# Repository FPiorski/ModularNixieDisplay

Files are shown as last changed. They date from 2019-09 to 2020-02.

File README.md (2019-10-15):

# Modular PCB for Z5730M Nixie tubes
#### Because ten small boards are better than a single big one
Schematics and board desing done in KiCad
##### ~~TODO for Rev 2:~~
* ~~Fix Z5730M footprint~~
  * ~~Widen mounting holes to account for desoldered tubes~~
  * ~~Bring mounting holes closer to center~~
* ~~Fix transistor pinout~~
  * ~~Change from Q_NPN_CBE to Q_NPN_BEC on the schematic~~
* ~~Reannotate components on the schematic~~
  * ~~Make R_n connect to Q_n and drive digit n~~
* ~~Add Rev 2 markings, of course~~

##### Revision 2 done!

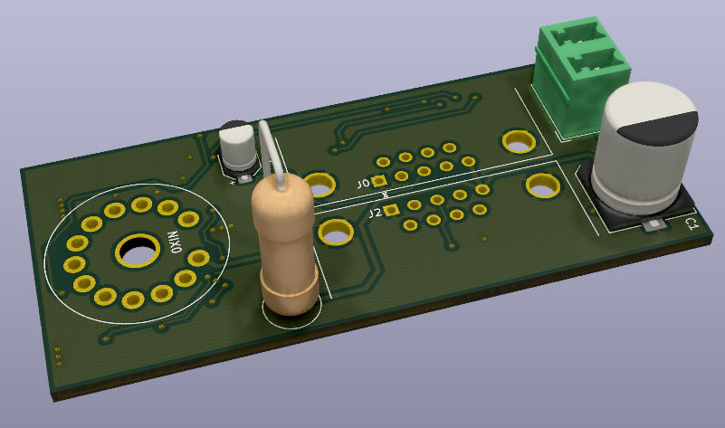
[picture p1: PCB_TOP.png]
top

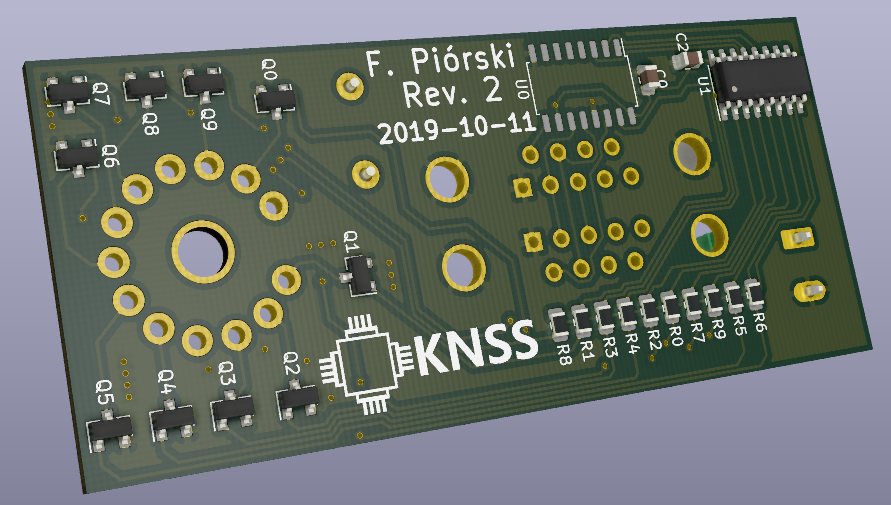
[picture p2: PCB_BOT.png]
bottom


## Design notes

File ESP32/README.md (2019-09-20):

# ESP32 Control software

### Because the Nixie boards are modular I though controlling them should reflect that

So I drive them with an ESP32 through UDP.

#### How to build

After installing [esp-idf](https://github.com/espressif/esp-idf), cloning this repo and exporting env variables ($IDF_PATH/export.sh) just configure your SSID and password, used pins, udp port, then build and flash.
```
idf.py menuconfig
idf.py build
idf.py -p PORTPATH flash
```

#### How to use
Just send a UDP packet to the ESP32 over WiFi containg what you want to display, colons are automatically converted to fives.
```
watch -n1 "date +%T%N | head -c10 | nc -u -q0 192.168.0.115 3333"
```

### How it works
It's literally the udp_server example with some added GPIO use for manually shifting out the data to chained 74HC595's, nothing fancy.

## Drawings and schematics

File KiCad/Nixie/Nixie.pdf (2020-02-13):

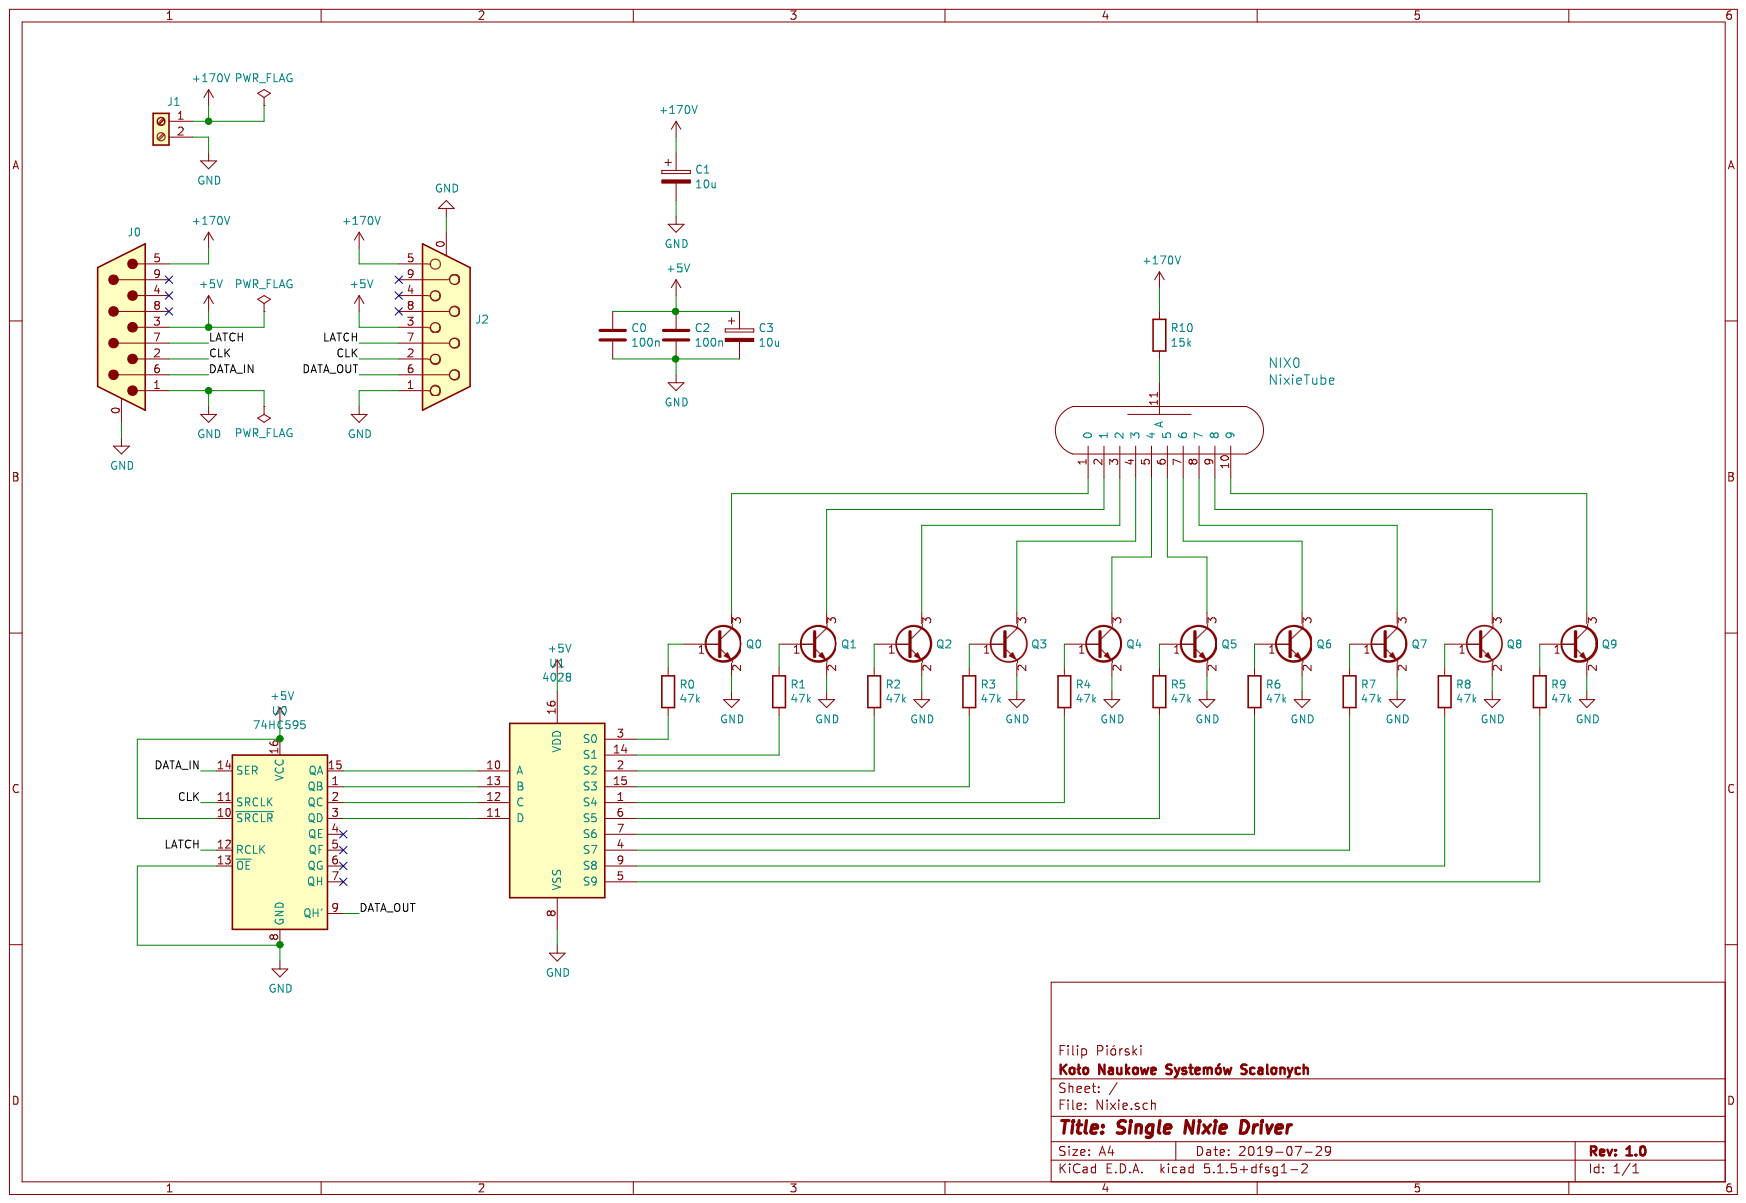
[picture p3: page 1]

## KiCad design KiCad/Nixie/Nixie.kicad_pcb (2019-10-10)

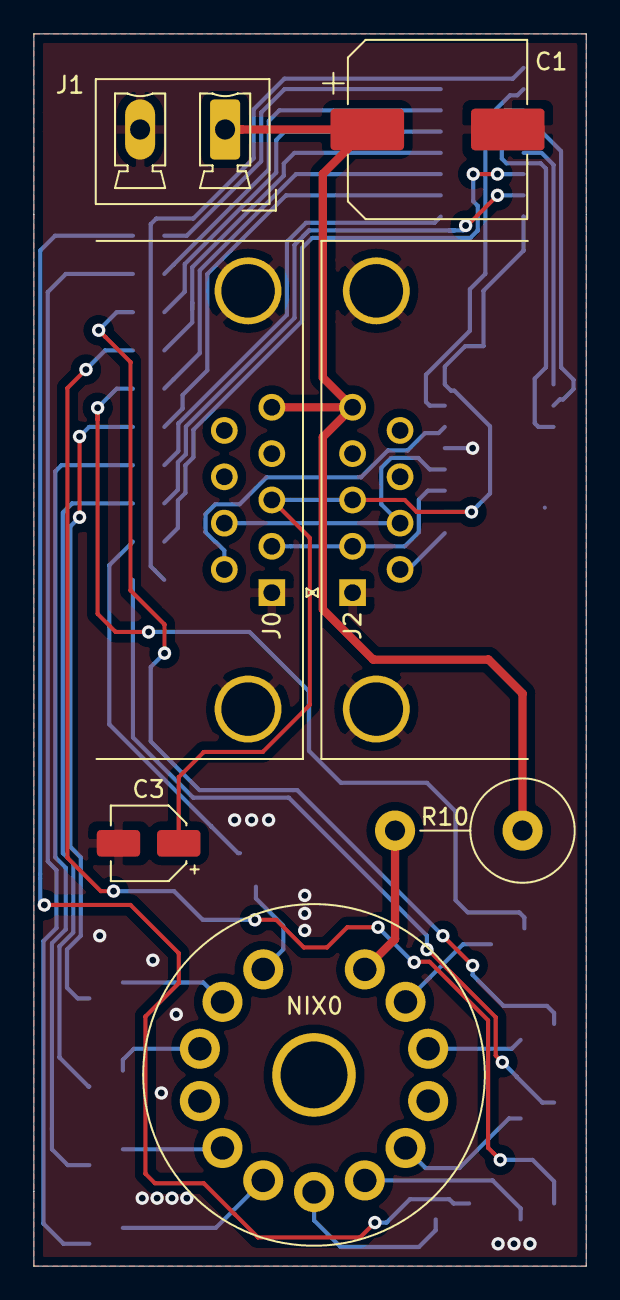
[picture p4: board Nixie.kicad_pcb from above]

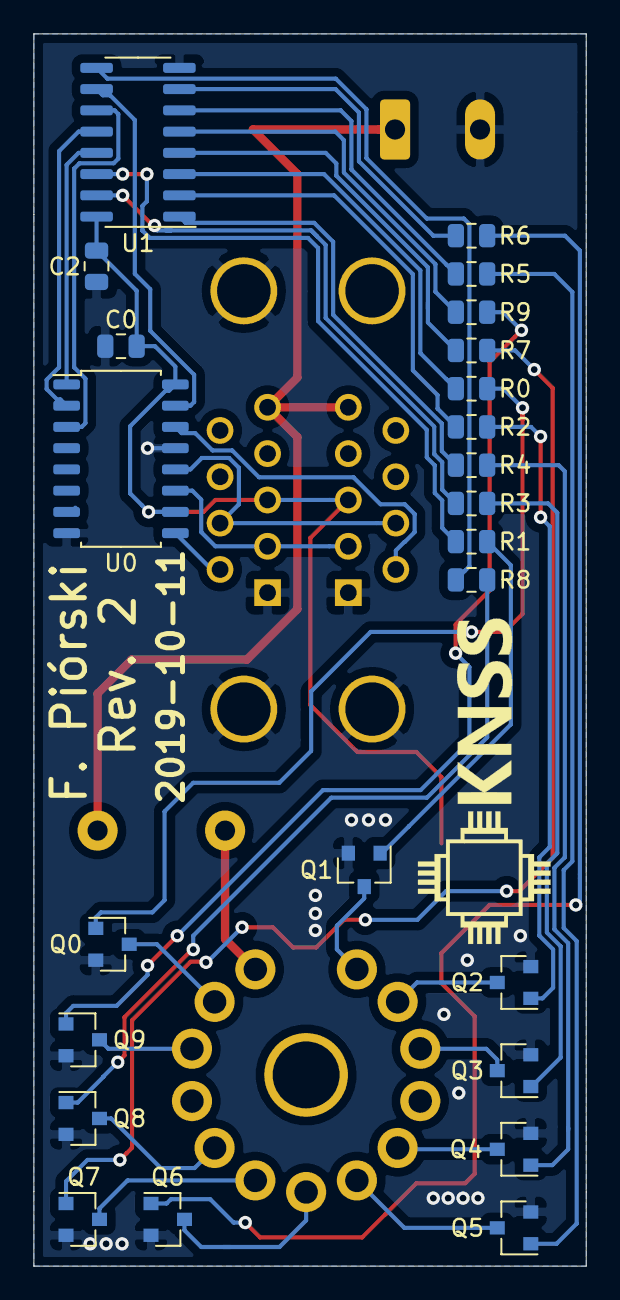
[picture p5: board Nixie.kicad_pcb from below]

Board: 2 copper layers, 33.0 x 73.7 mm, 31 parts (24 on the bottom side), 42 nets.

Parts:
C0, C2: 100n; C_0805_2012Metric
C1: 10u; CP_Elec_10x12.5
C3: 10u; CP_Elec_4x5.4
J0: DB9_Male_MountingHoles; DSUB-9_Female_Horizontal_P2.77x2.84mm_EdgePinOffset7.70mm_H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
J1: Screw_Terminal_01x02; PhoenixContact_MCV_1,5_2-G-5.08_1x02_P5.08mm_Vertical
J2: DB9_Female_MountingHoles; DSUB-9_Male_Horizontal_P2.77x2.84mm_EdgePinOffset7.70mm_Hou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
NIX0: NixieTube; Z5730M
Q0, Q1, Q2, Q3, Q4, Q5, Q6, Q7, Q8, Q9: Q_NPN_BEC; SOT-23
R0, R1, R2, R3, R4, R5, R6, R7, R8, R9: 47k; R_0805_2012Metric
R10: 15k; R_Axial_DIN0617_L17.0mm_D6.0mm_P7.62mm_Vertical
U0: 74HC595; SOP-16_4.55x10.3mm_P1.27mm
U1: 4028; SOIC-16_3.9x9.9mm_P1.27mm

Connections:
+5V: C0.1, C2.1, C3.1, J0.3, J2.3, U0.10, U0.16, U1.16
+170V: C1.1, J0.5, J1.1, J2.5, R10.1
/CLK: J0.2, J2.2, U0.11
/DATA_IN: J0.6, U0.14
/DATA_OUT: J2.6, U0.9
/LATCH: J0.7, J2.7, U0.12
GND: C0.2, C1.2, C2.2, C3.2, J0.0, J0.1, J1.2, J2.0, J2.1, Q0.2, Q1.2, Q2.2, Q3.2, Q4.2, Q5.2, Q6.2, Q7.2, Q8.2, Q9.2, U0.8, U0.13, U1.8
unnamed: NIX0.1, Q0.3
unnamed: NIX0.2, Q1.3
unnamed: NIX0.3, Q2.3
unnamed: NIX0.4, Q3.3
unnamed: NIX0.5, Q4.3
unnamed: NIX0.6, Q5.3
unnamed: NIX0.7, Q6.3
unnamed: NIX0.8, Q7.3
unnamed: NIX0.9, Q8.3
unnamed: NIX0.10, Q9.3
unnamed: NIX0.11, R10.2
unnamed: Q0.1, R0.1
unnamed: Q1.1, R1.1
unnamed: Q2.1, R2.1
unnamed: Q3.1, R3.1
unnamed: Q4.1, R4.1
unnamed: Q5.1, R5.1
unnamed: Q6.1, R6.1
unnamed: Q7.1, R7.1
unnamed: Q8.1, R8.1
unnamed: Q9.1, R9.1
unnamed: R0.2, U1.3
unnamed: R1.2, U1.14
unnamed: R2.2, U1.2
unnamed: R3.2, U1.15
unnamed: R4.2, U1.1
unnamed: R5.2, U1.6
unnamed: R6.2, U1.7
unnamed: R7.2, U1.4
unnamed: R8.2, U1.9
unnamed: R9.2, U1.5
unnamed: U0.1, U1.13
unnamed: U0.2, U1.12
unnamed: U0.3, U1.11
unnamed: U0.15, U1.10

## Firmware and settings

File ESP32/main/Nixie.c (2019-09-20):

//This file is just the UDP server example that takes the recieved data and outputs it to connected shift registers
#include <string.h>
#include <sys/param.h>
#include "freertos/FreeRTOS.h"
#include "freertos/task.h"
#include "esp_system.h"
#include "esp_wifi.h"
#include "esp_event.h"
#include "esp_log.h"
#include "nvs_flash.h"
#include "tcpip_adapter.h"
#include "protocol_examples_common.h"

#include "lwip/err.h"
#include "lwip/sockets.h"
#include "lwip/sys.h"
#include <lwip/netdb.h>

#include "driver/gpio.h"

#define PORT CONFIG_PORT

#define GPIO_OUTPUT_IO_DATA     CONFIG_DATA_PIN
#define GPIO_OUTPUT_IO_CLK      CONFIG_CLK_PIN
#define GPIO_OUTPUT_IO_LATCH    CONFIG_LATCH_PIN
#define GPIO_OUTPUT_PIN_SEL  ((1ULL<<GPIO_OUTPUT_IO_DATA) | (1ULL<<GPIO_OUTPUT_IO_LATCH) | (1ULL<<GPIO_OUTPUT_IO_CLK))

int shiftOut(char c);

static const char *TAG = "Nixie";

static void udp_server_task(void *pvParameters)
{
    char rx_buffer[128];
    char addr_str[128];
    int addr_family;
    int ip_protocol;

    while (1) {

#ifdef CONFIG_IPV4
        struct sockaddr_in dest_addr;
        dest_addr.sin_addr.s_addr = htonl(INADDR_ANY);
        dest_addr.sin_family = AF_INET;
        dest_addr.sin_port = htons(PORT);
        addr_family = AF_INET;
        ip_protocol = IPPROTO_IP;
        inet_ntoa_r(dest_addr.sin_addr, addr_str, sizeof(addr_str) - 1);
#else // IPV6
        struct sockaddr_in6 dest_addr;
        bzero(&dest_addr.sin6_addr.un, sizeof(dest_addr.sin6_addr.un));
        dest_addr.sin6_family = AF_INET6;
        dest_addr.sin6_port = htons(PORT);
        addr_family = AF_INET6;
        ip_protocol = IPPROTO_IPV6;
        inet6_ntoa_r(dest_addr.sin6_addr, addr_str, sizeof(addr_str) - 1);
#endif

        int sock = socket(addr_family, SOCK_DGRAM, ip_protocol);
        if (sock < 0) {
            ESP_LOGE(TAG, "Unable to create socket: errno %d", errno);
            break;
        }
        ESP_LOGI(TAG, "Socket created");

        int err = bind(sock, (struct sockaddr *)&dest_addr, sizeof(dest_addr));
        if (err < 0) {
            ESP_LOGE(TAG, "Socket unable to bind: errno %d", errno);
        }
        ESP_LOGI(TAG, "Socket bound, port %d", PORT);

        //GPIO config

        gpio_config_t io_conf;
        io_conf.intr_type = GPIO_PIN_INTR_DISABLE;
        io_conf.mode = GPIO_MODE_OUTPUT;
        io_conf.pin_bit_mask = GPIO_OUTPUT_PIN_SEL;
        io_conf.pull_down_en = 0;
        io_conf.pull_up_en = 0;
        gpio_config(&io_conf);

        while (1) {

            // ESP_LOGI(TAG, "Waiting for data");
            struct sockaddr_in6 source_addr; // Large enough for both IPv4 or IPv6
            socklen_t socklen = sizeof(source_addr);
            int len = recvfrom(sock, rx_buffer, sizeof(rx_buffer) - 1, 0, (struct sockaddr *)&source_addr, &socklen);

            // Error occurred during receiving
            if (len < 0) {
                ESP_LOGE(TAG, "recvfrom failed: errno %d", errno);
                break;
            }
            // Data received
            else {
                // Get the sender's ip address as string
                if (source_addr.sin6_family == PF_INET) {
                    inet_ntoa_r(((struct sockaddr_in *)&source_addr)->sin_addr.s_addr, addr_str, sizeof(addr_str) - 1);
                } else if (source_addr.sin6_family == PF_INET6) {
                    inet6_ntoa_r(source_addr.sin6_addr, addr_str, sizeof(addr_str) - 1);
                }

                rx_buffer[len] = 0; // Null-terminate whatever we received and treat like a string...
                // ESP_LOGI(TAG, "Received %d bytes from %s:", len, addr_str);
                // ESP_LOGI(TAG, "%s", rx_buffer);

                for (int i=0; i<len; ++i)
                {
                    if (rx_buffer[i] == ':') {
                        rx_buffer[i] = '6';
                        // ESP_LOGI(TAG, "Changed a \":\" to \"5\" for displaying");
                    }
                }

                gpio_set_level(GPIO_OUTPUT_IO_LATCH, 0);
                // ESP_LOGI(TAG, "Latch (GPIO%i) pulled low", GPIO_OUTPUT_IO_LATCH);
                for (int i=len-2; i>=0; --i)
                {
                    shiftOut(rx_buffer[i]);
                }
                gpio_set_level(GPIO_OUTPUT_IO_LATCH, 1);
                // ESP_LOGI(TAG, "Latch (GPIO%i) pulled high", GPIO_OUTPUT_IO_LATCH);

                int err = sendto(sock, rx_buffer, len, 0, (struct sockaddr *)&source_addr, sizeof(source_addr));
                if (err < 0) {
                    ESP_LOGE(TAG, "Error occurred during sending: errno %d", errno);
                    break;
                }
            }
        }

        if (sock != -1) {
            ESP_LOGE(TAG, "Shutting down socket and restarting...");
            shutdown(sock, 0);
            close(sock);
        }
    }
    vTaskDelete(NULL);
}

void app_main(void)
{
    ESP_ERROR_CHECK(nvs_flash_init());
    tcpip_adapter_init();
    ESP_ERROR_CHECK(esp_event_loop_create_default());

    /* This helper function configures Wi-Fi or Ethernet, as selected in menuconfig.
     * Read "Establishing Wi-Fi or Ethernet Connection" section in
     * examples/protocols/README.md for more information about this function.
     */
    ESP_ERROR_CHECK(example_connect());

    xTaskCreate(udp_server_task, "udp_server", 4096, NULL, 5, NULL);
}

int shiftOut(char c)
{
    // ESP_LOGI(TAG, "Shifting out \"%c\" MSB-first", c);
    for (int i=7; i>=0; --i) {
        // ESP_LOGI(TAG, "Pulling data (GPIO%i) to bit %i, which is bit %i, counting from LSB", GPIO_OUTPUT_IO_DATA, (c>>i)&1, i);
        gpio_set_level(GPIO_OUTPUT_IO_DATA, (c>>i)&1);
        // ESP_LOGI(TAG, "Pulling clock (GPIO%i) high", GPIO_OUTPUT_IO_CLK);
        gpio_set_level(GPIO_OUTPUT_IO_CLK, 1);
        // ESP_LOGI(TAG, "Pulling clock (GPIO%i) low", GPIO_OUTPUT_IO_CLK);
        gpio_set_level(GPIO_OUTPUT_IO_CLK, 0);
    }

    return 0;
}

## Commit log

2019-07-29 First version of the schematic, to be changed later
    [Nixie.sch]
2019-07-29 First PCB draft
    [Nixie.sch]
2019-07-31 PCB routing part 1
    [Nixie.kicad_pcb, Nixie.sch]
2019-08-07 Finished the board
    [Nixie.kicad_pcb, Nixie.sch]
2019-09-20 Added ESP32 code
2019-10-10 Revision 2
    [Nixie.kicad_pcb]
2019-10-15 Finally added the BoM
2020-02-13 Minor Schematic Change
    [Nixie.sch]
2020-02-13 further git-KiCad integration
2020-02-13 Added a pdf export of the schematic
